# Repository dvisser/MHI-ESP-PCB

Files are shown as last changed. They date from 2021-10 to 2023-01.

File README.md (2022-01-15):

# MHI-ESP-PCB
ESP8266 based WiFi module for MHI split-system air conditioners that communicates directly with the air conditioner via the indoor unit PCB "CNS" (spi data) and "CNE" (display board data) connectors.

The "CNE" connection (between IR receiver board and the indoor unit control board) is to add features that are not accessible over the SPI connection on the "CNS" header (such as 3D Auto, some vane controls, etc).

This module is designed to run firmware developed jointly with TZB (thezerobeast) which is available here https://github.com/TheZeroBeast/ACWiFi

This PCB was designed and developed using KiCAD :-)

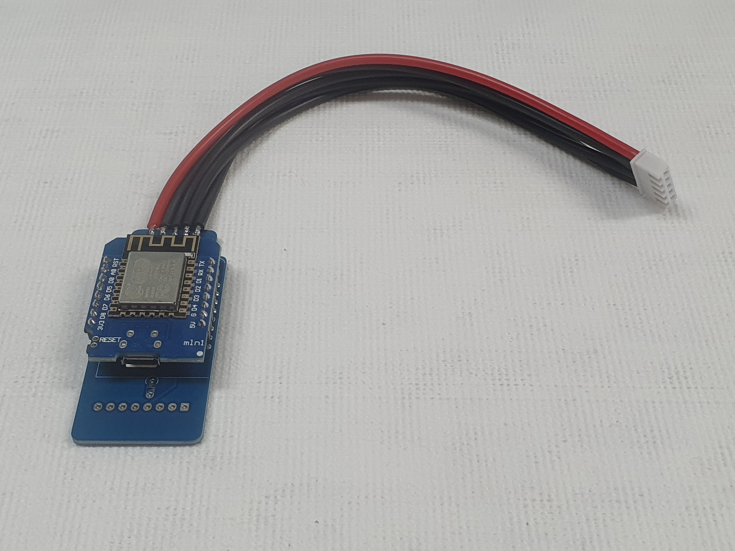
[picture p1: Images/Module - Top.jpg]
Module - Top


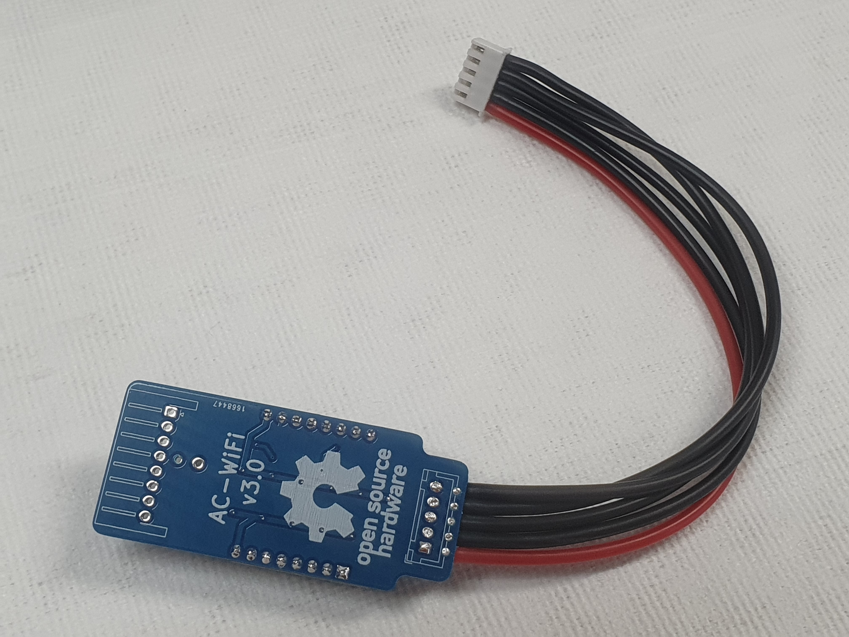
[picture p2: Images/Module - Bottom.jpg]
Module - Bottom


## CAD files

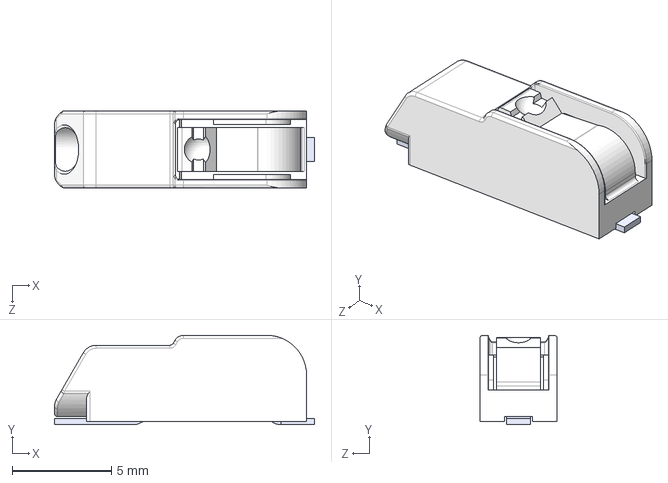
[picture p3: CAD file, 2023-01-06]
2060-451_998-404.step
13.1 x 4.50 x 3.90 mm

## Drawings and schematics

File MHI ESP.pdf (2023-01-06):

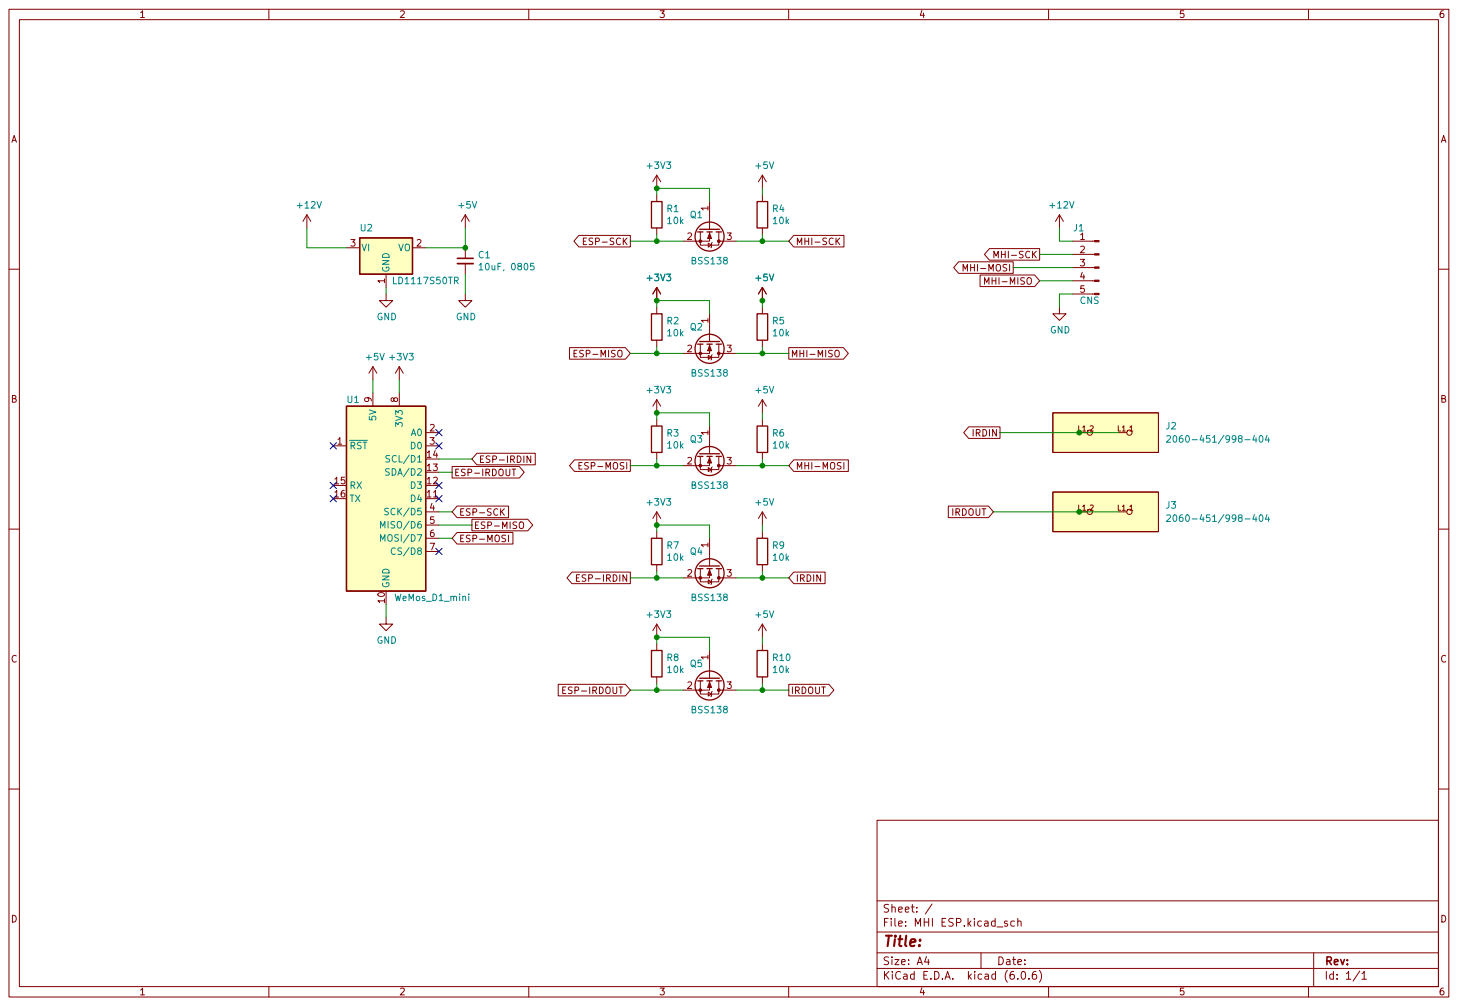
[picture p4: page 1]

ESP-MOSI ESP-SCK
ESP-MISO

File: MHI ESP.kicad_sch Sheet: /
Id: 1/1 Title:

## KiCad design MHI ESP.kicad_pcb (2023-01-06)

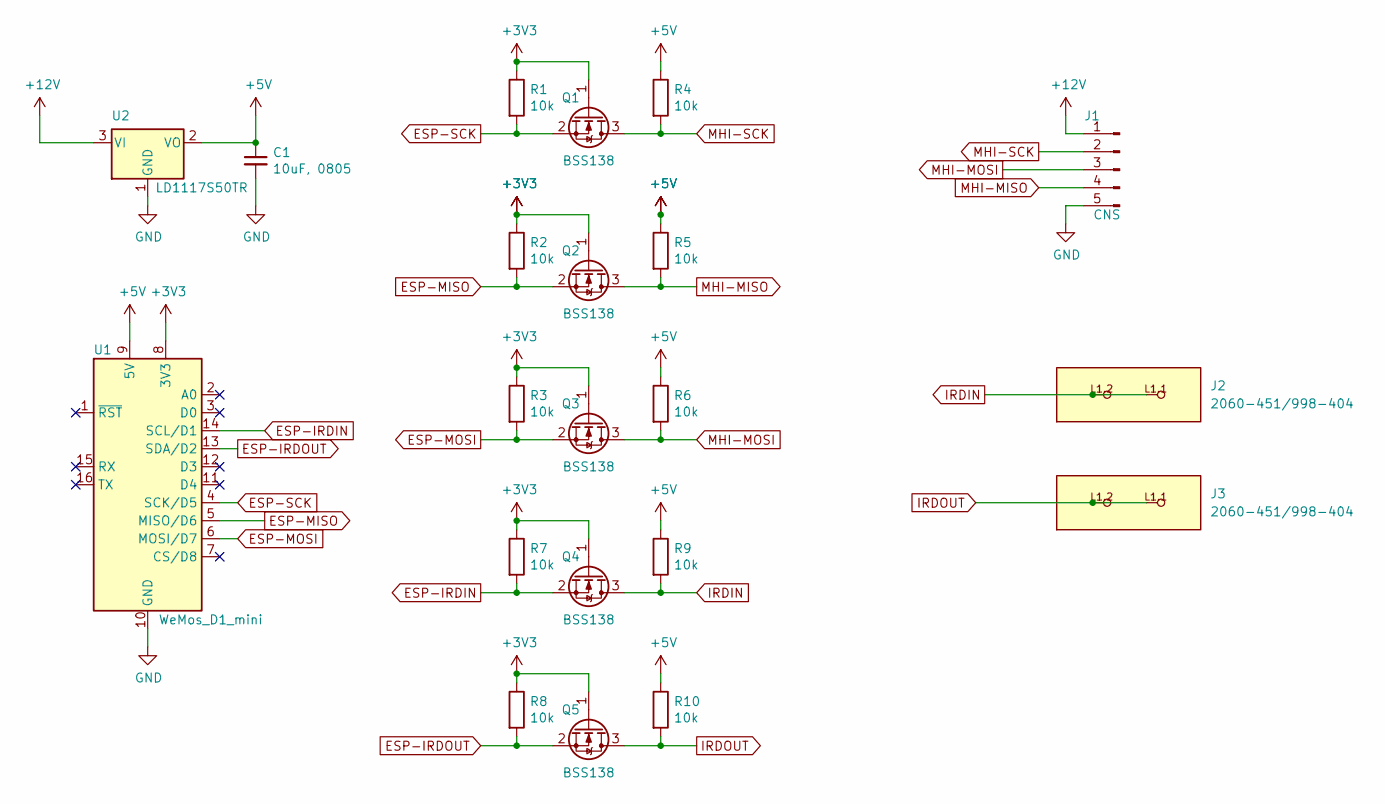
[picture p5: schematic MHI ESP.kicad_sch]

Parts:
C1: 10uF, 0805; C_0805_2012Metric
J1: CNS; JST_XH_B5B-XH-A_1x05_P2.50mm_Vertical
J2, J3: 2060-451/998-404; P-2060-451/998-404
Q1, Q2, Q3, Q4, Q5: BSS138; SOT-23
R1, R2, R3, R4, R5, R6, R7, R8, R9, R10: 10k; R_0805_2012Metric
U1: WeMos_D1_mini; WEMOS_D1_mini_light
U2: LD1117S50TR; SOT-223-3_TabPin2

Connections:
+3V3: Q1.1 (G), Q2.1 (G), Q3.1 (G), Q4.1 (G), Q5.1 (G), R1.1, R2.1, R3.1, R7.1, R8.1, U1.8 (3V3)
+5V: C1.1, R4.1, R5.1, R6.1, R9.1, R10.1, U1.9 (5V), U2.2 (VO)
+12V: J1.1, U2.3 (VI)
ESP-IRDIN: Q4.2 (S), R7.2, U1.14 (SCL/D1)
ESP-IRDOUT: Q5.2 (S), R8.2, U1.13 (SDA/D2)
ESP-MISO: Q2.2 (S), R2.2, U1.5 (MISO/D6)
ESP-MOSI: Q3.2 (S), R3.2, U1.6 (MOSI/D7)
ESP-SCK: Q1.2 (S), R1.2, U1.4 (SCK/D5)
GND: C1.2, J1.5, U1.10 (GND), U2.1 (GND)
IRDIN: J2.L1.1, J2.L1.2, Q4.3 (D), R9.2
IRDOUT: J3.L1.1, J3.L1.2, Q5.3 (D), R10.2
MHI-MISO: J1.4, Q2.3 (D), R5.2
MHI-MOSI: J1.3, Q3.3 (D), R6.2
MHI-SCK: J1.2, Q1.3 (D), R4.2

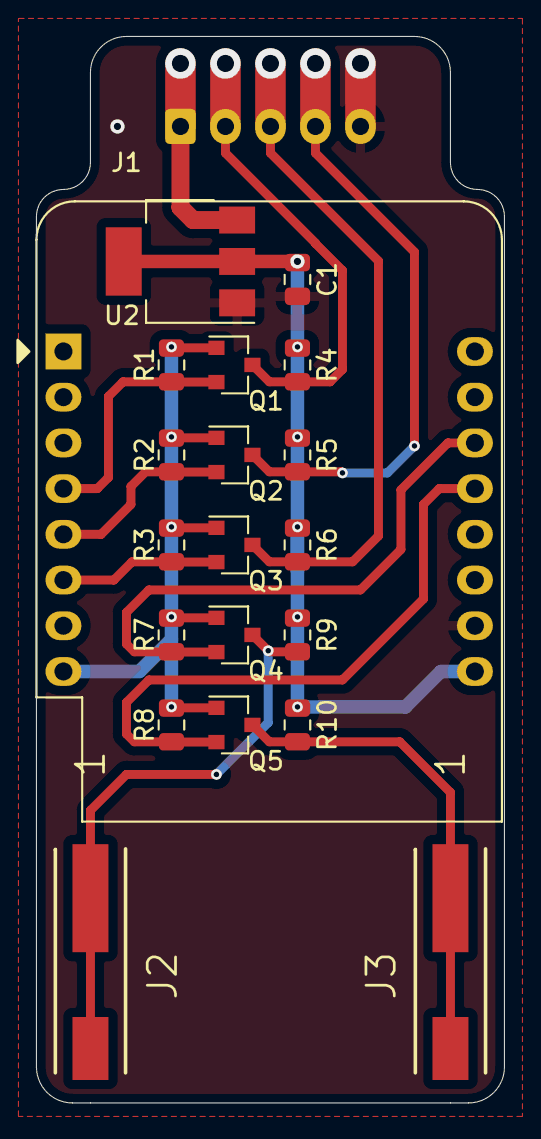
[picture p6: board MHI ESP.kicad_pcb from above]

Board: 2 copper layers, 26.0 x 59.2 mm, 21 parts (1 on the bottom side), 14 nets.

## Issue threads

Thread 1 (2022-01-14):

Missing information on CNE

synnack, 2022-01-14:
Hi,

Cool project!
I'm considering assembling something like this PCB or https://github.com/absalom-muc/MHI-AC-Ctrl/blob/master/Hardware.md.

The difference is the presence of something that taps into the infrared port via the CNE connector.

But what I'm missing is:
1. What does the infrared port allow that the SPI does not have?
2. How is it wired? Is it a tap or Man-in-the-Middle ?

Looking forward to your feedback (also in the .md? :)

dvisser, 2022-01-14:
Hi,

Answers for you:

1. Our device is a man-in-the-middle so to speak, the firmware repeats any infrared signals from a remote to the unit. The main reason we added this was that "3d auto" isnt available over SPI (there may be some other functions also but this was the main one).

2. You can either cut a wire, or unplug the cable from the IR board in the head unit and plug it into our module and then make up a cable from our module and plug it into the control board where the IR board was originally plugged in.

Hope that makes sense?

Thanks,
Dan

synnack, 2022-01-14:
Yes, that makes perfect sense. I've also noticed that not all fan modes are available over SPI, but I figured that was just some missing reverse-engineering. Like vanes left/right and I think one of the fan speeds might be missing. Kind of weird that SPI would not have that, though.

dvisser, 2022-01-14:
Yeah the vanes you mention arent available over SPI either from memory. Hence the need to inject data onto the IR line.

dvisser, 2022-01-14:
Think we have added the missing fan speed over SPI though.

dvisser, 2022-01-14:
@TheZeroBeast the above that I have said RE firmware is correct isn't it?

dvisser, 2022-01-14:
and yes @synnack, I need to update the readme.md :-) thanks for the reminder!

TheZeroBeast, 2022-01-14:
Hey @synnack,

Yeah @dvisser, that’s right, I have auto fan going over IR as it’s not implemented on SPI.

dvisser, 2022-01-14:
ah right, well there ya go.

@synnack OK for me to close this issue now?

synnack, 2022-01-14:
@dvisser If you don't need the reminder to update the .md files, you can close it. I got what I need ;-)

dvisser, 2022-01-15:
readme.md updated

Closed 2022-01-15.

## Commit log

2021-09-08 Remove TXB0104 IC, DS18B20 IC and change 5V IC
    [MHI ESP.sch]
2021-09-08 Re-annotate schematic and update components on PCB, ready for new track layout
    [MHI ESP.kicad_pcb, MHI ESP.sch]
2021-09-08 Update connector footprint to 05JQ-BT to accomodate non-cabled installs
    [MHI ESP.sch]
2021-09-08 Ready to route PCB v2.0
    [MHI ESP.kicad_pcb]
2021-09-08 PCB v2.0 - routing completed
    [MHI ESP.kicad_pcb]
2021-09-10 Minor silkscreen updates and Gerber / Drill File Generation
    [MHI ESP-B_Cu.gbr, MHI ESP-B_Mask.gbr, MHI ESP-B_Paste.gbr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]
2021-09-12 Start of IR data capturing idea...
    [MHI ESP.sch]
2021-09-13 Reconfigured J2 and J3 to suit cable out to CNE.
    [MHI ESP.sch]
2021-09-14 Added IR data injection circuit and headers
    [MHI ESP-B_Cu.gbr, MHI ESP-B_Mask.gbr, MHI ESP-B_Paste.gbr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]
2021-09-14 corrected J2 and J3 designator visibility
    [MHI ESP-B_Cu.gbr, MHI ESP-B_Mask.gbr, MHI ESP-B_Paste.gbr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]
2021-09-14 Added PDF schematic
2023-01-06 Updated to v4.0
    Added WAGO terminals for IR signal in and out.
    [2060-451_998-404.step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]
